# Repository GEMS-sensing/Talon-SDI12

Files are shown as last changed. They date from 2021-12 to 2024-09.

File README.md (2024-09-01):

<!-- [![DOI](https://zenodo.org/badge/678911830.svg)](https://zenodo.org/doi/10.5281/zenodo.13377368) -->

# Talon-SDI12
Talon daughterboard for [Flight data logger](https://github.com/GEMS-sensing/DFM_-_Flight?tab=readme-ov-file). Designed to interface with [Kestrel](https://github.com/GEMS-sensing/Project-Kestrel) main board. This board is designed to provide data logger with support to interface with [SDI-12 communication standard](https://www.sdi-12.org/current_specification/SDI-12%20Specification%201.4%20February%2020%202023.pdf) for environmental sensors.

# Repo Roadmap
#### [Documents](Documents/) 

General document and image storage for repo and README

#### [Hardware](Hardware/)

Current board files (Eagle), Bill of Materials (BoM), and other design documents

#### [Production](Production/)

Contains the various Gerber and pick and place files required to have the Printed Circuit Boards (PCBs) manufactured or populated 

#### [Software](Software/)

The software associated with the piece of hardware, this is usually diagnostic software used for verifying or investigating the hardware

<!-- #### [Mechanical](Mechanical/)

Mechanical design files and assembly documents -->

<!-- #### [Testing](Testing/)

Scripts and results from the testing process and development process. Contains more detailed information about documented issues among other testing. 
 -->

## Overview
* **Type:** Talon
* **Interfaces:** SDI-12
* **Release Version:** v1.4 - 2022/04/25

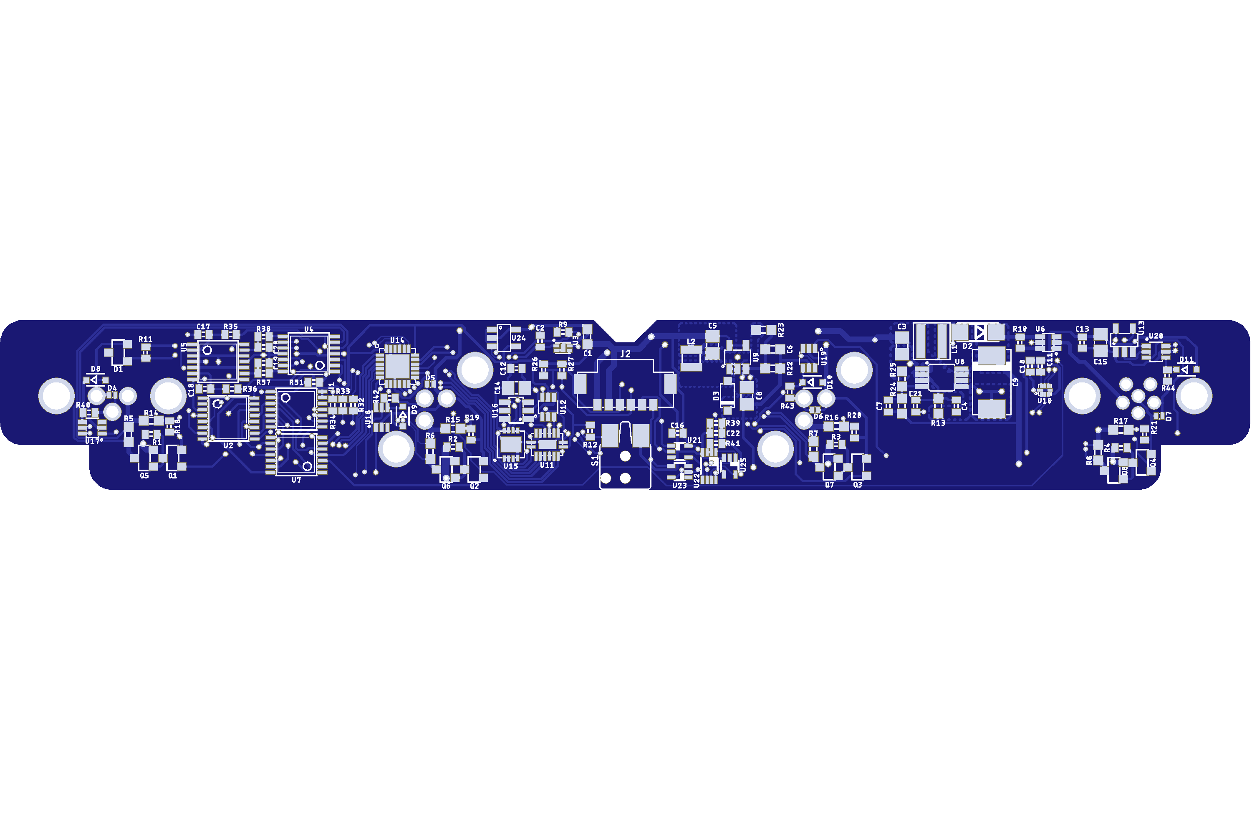
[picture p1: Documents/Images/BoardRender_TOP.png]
PCB render image, top


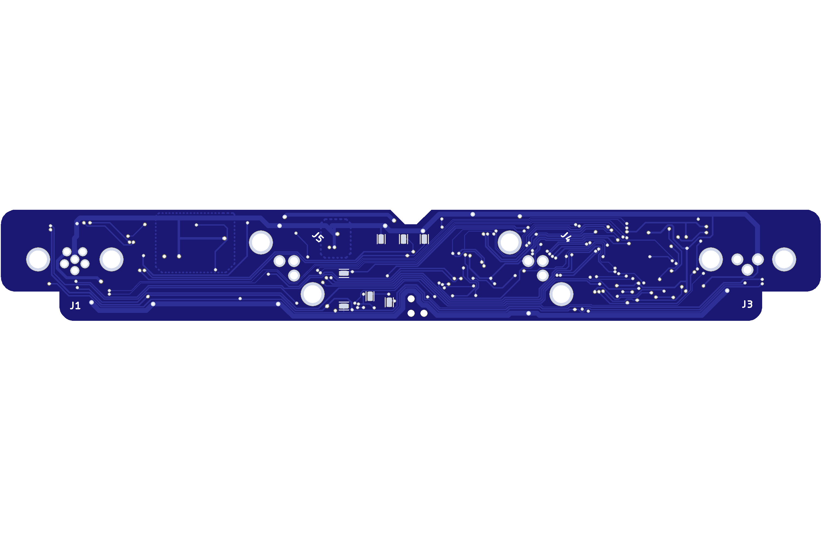
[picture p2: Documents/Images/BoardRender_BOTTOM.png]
PCB render image, bottom


<!-- ![Haar v0.0 - Bottom](Documents/Images/Haar_0v0_Bottom_Cropped.jpg) -->

## Features
### On-Board
* SDI-12 ports (x3)
* Dedicated Apogee sensor port (x1)
	* Supports SDI-12 communication and analog voltage input
	* Supports [Apogee pinout standard](https://www.apogeeinstruments.com/apogee-wiring-guide/)
* Port level current limit
	* Custom designed automatic current limit 
	* support for current and voltage measurement for each port
* Data and power control for each port
* Loopback support to perform SDI-12 communication diagnostics 
* EEPROM with UUID built in - can store additional values defined by firmware to track offsets, etc
* ESD protected inputs

<!-- ### Interface
* I<sup>2</sup>C
* M12 circular connector  -->

<!-- <picture>
  <source media="(prefers-color-scheme: dark)" srcset="Documents/Pinout_LIGHT.png">
  <img alt="Haar Connector Pinout" src="Documents/Pinout.png">
</picture> -->

<!-- ## Specifications
* **Voltage - Supply:** 3.3V
* **Voltage - Logic:** 3.3V
* **Input Current (Avg, 1s period): 30.95&mu;A @ 3.3V**
* **Input Current (Avg, 5s period): 107.43&mu;A @ 3.3V**
* **Input Current (Max): 0.45mA @ 3.3V**

#### Sensor
**Temperature** [^1]
* Range: -40 ~ 125°C 
* Accuracy: &plusmn; 0.2°C
* Repeatability: &plusmn; 0.04°C

**Pressure** [^2]
* Range: 300 ~ 1200 hPa  
* Accuracy: &plusmn; 1 hPa
* Repeatability: &plusmn; 0.06 hPa

**Humidity** [^1]
* Range: 0 ~ 100%
* Accuracy: &plusmn; 2%
* Repeatability: 0.08%

[^1]: [SHT31 Datasheet](https://sensirion.com/media/documents/213E6A3B/63A5A569/Datasheet_SHT3x_DIS.pdf)
[^2]: [DPS368 Datasheet](https://www.infineon.com/dgdl/Infineon-DPS368-DS-v01_00-EN.pdf?fileId=5546d46269e1c019016a0c45105d4b40) -->

<!-- ## Version History

`v0.0` - Initial primal version with screw terminal

`v0.1` - Initial 'hard mount' version, using M12 connector

`v1.0` - Removed pullup select[^3], added logic level buffer and voltage reg on input

`v1.1` - Moved via away from connector pads to prevent bridging when soldering 

`v2.0` - Fixed issue with address select jumper[^3] -->

<!-- ## Jumper Settings 

> [!IMPORTANT]
> Jumper settings valid for version `v2.0` and beyond[^3]

[^3]: See Errata

**Configuration Jumpers**
| Jumper | Purpose | Open | Closed | Default | 
| --- | --- | --- | --- | ----- |
| `JP1` | I<sup>2</sup>C Address Select | Base Address<sup>&dagger;</sup> | Alt Address<sup>&Dagger;</sup> | Open |

&dagger; SHT31 = `0x44`, DPS368 = `0x76`

&Dagger; SHT31 = `0x44`, DPS368 = `0x77`
 -->

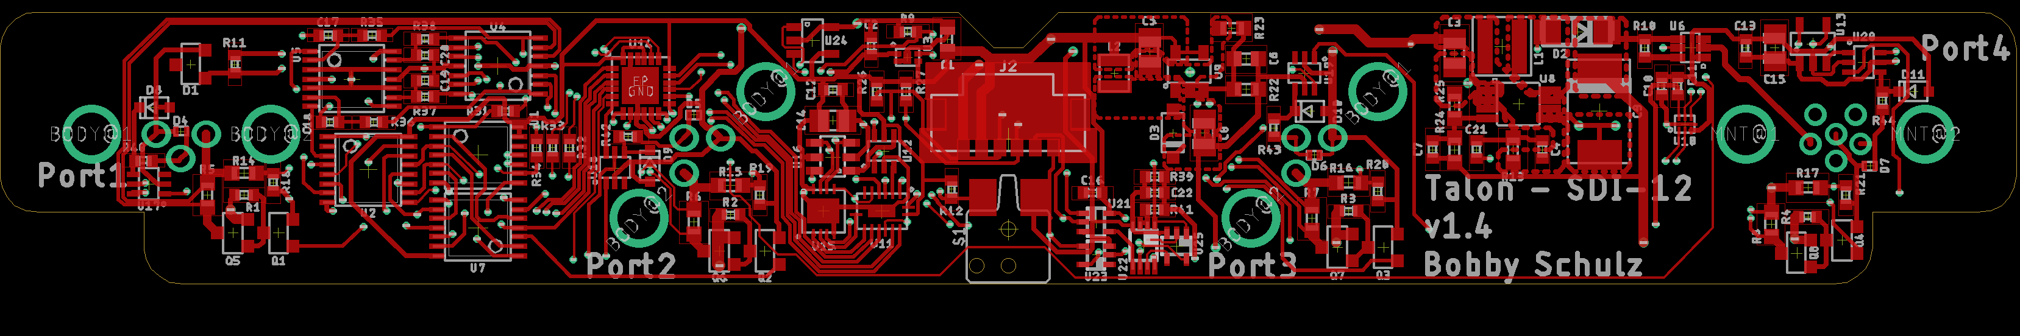
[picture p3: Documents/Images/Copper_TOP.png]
PCB trace CAD image, top


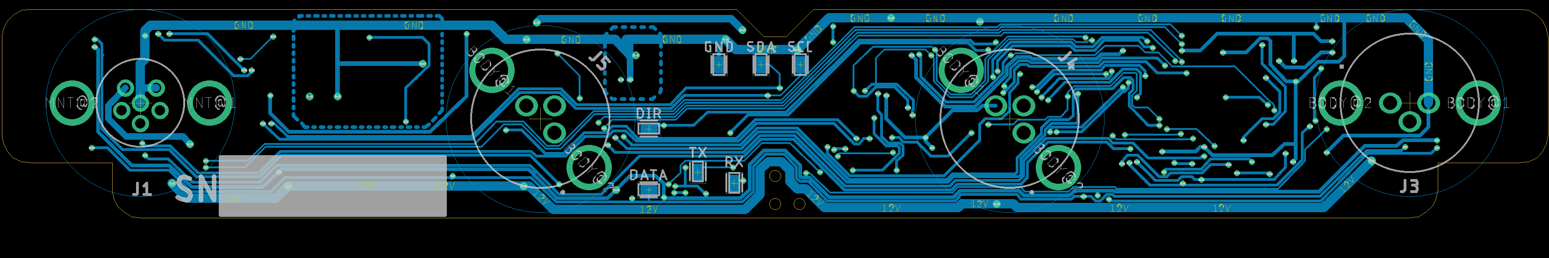
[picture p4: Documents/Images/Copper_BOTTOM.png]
PCB trace CAD, bottom


## Known Issues/Errata

None
<!-- #### Solder Jumper Stencil

**Version Affected:** All

**Issue:** Solar input does not support very low impedance sources (e.g. lead acid battery) - see details in issue [#20](https://github.com/GEMS-sensing/Project-Kestrel/issues/20)

**Workaround:** 

* Avoid use of low impedance batteries for input
* Include series impedance to prevent current spikes (not desirable)
* Perform board patch described in issue [#20](https://github.com/GEMS-sensing/Project-Kestrel/issues/20) -->

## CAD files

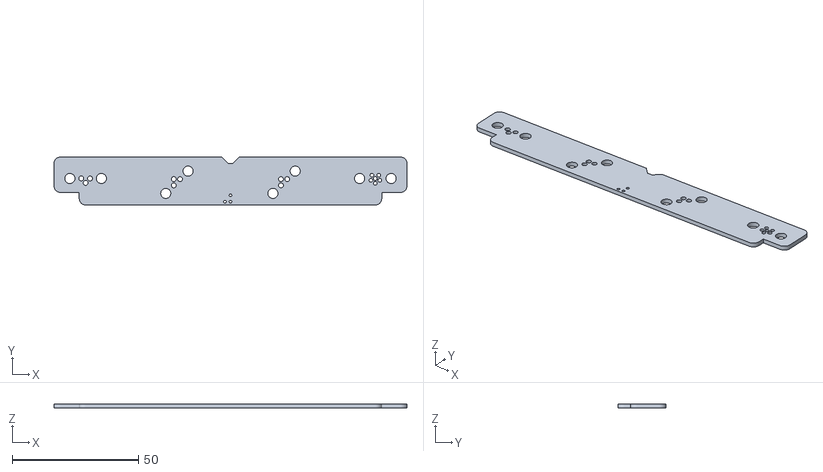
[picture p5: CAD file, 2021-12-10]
Hardware/Talon_SDI12_1v1.STL
140.0 x 19.0 x 1.57

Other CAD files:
Hardware/Talon_SDI12_1v1.dxf

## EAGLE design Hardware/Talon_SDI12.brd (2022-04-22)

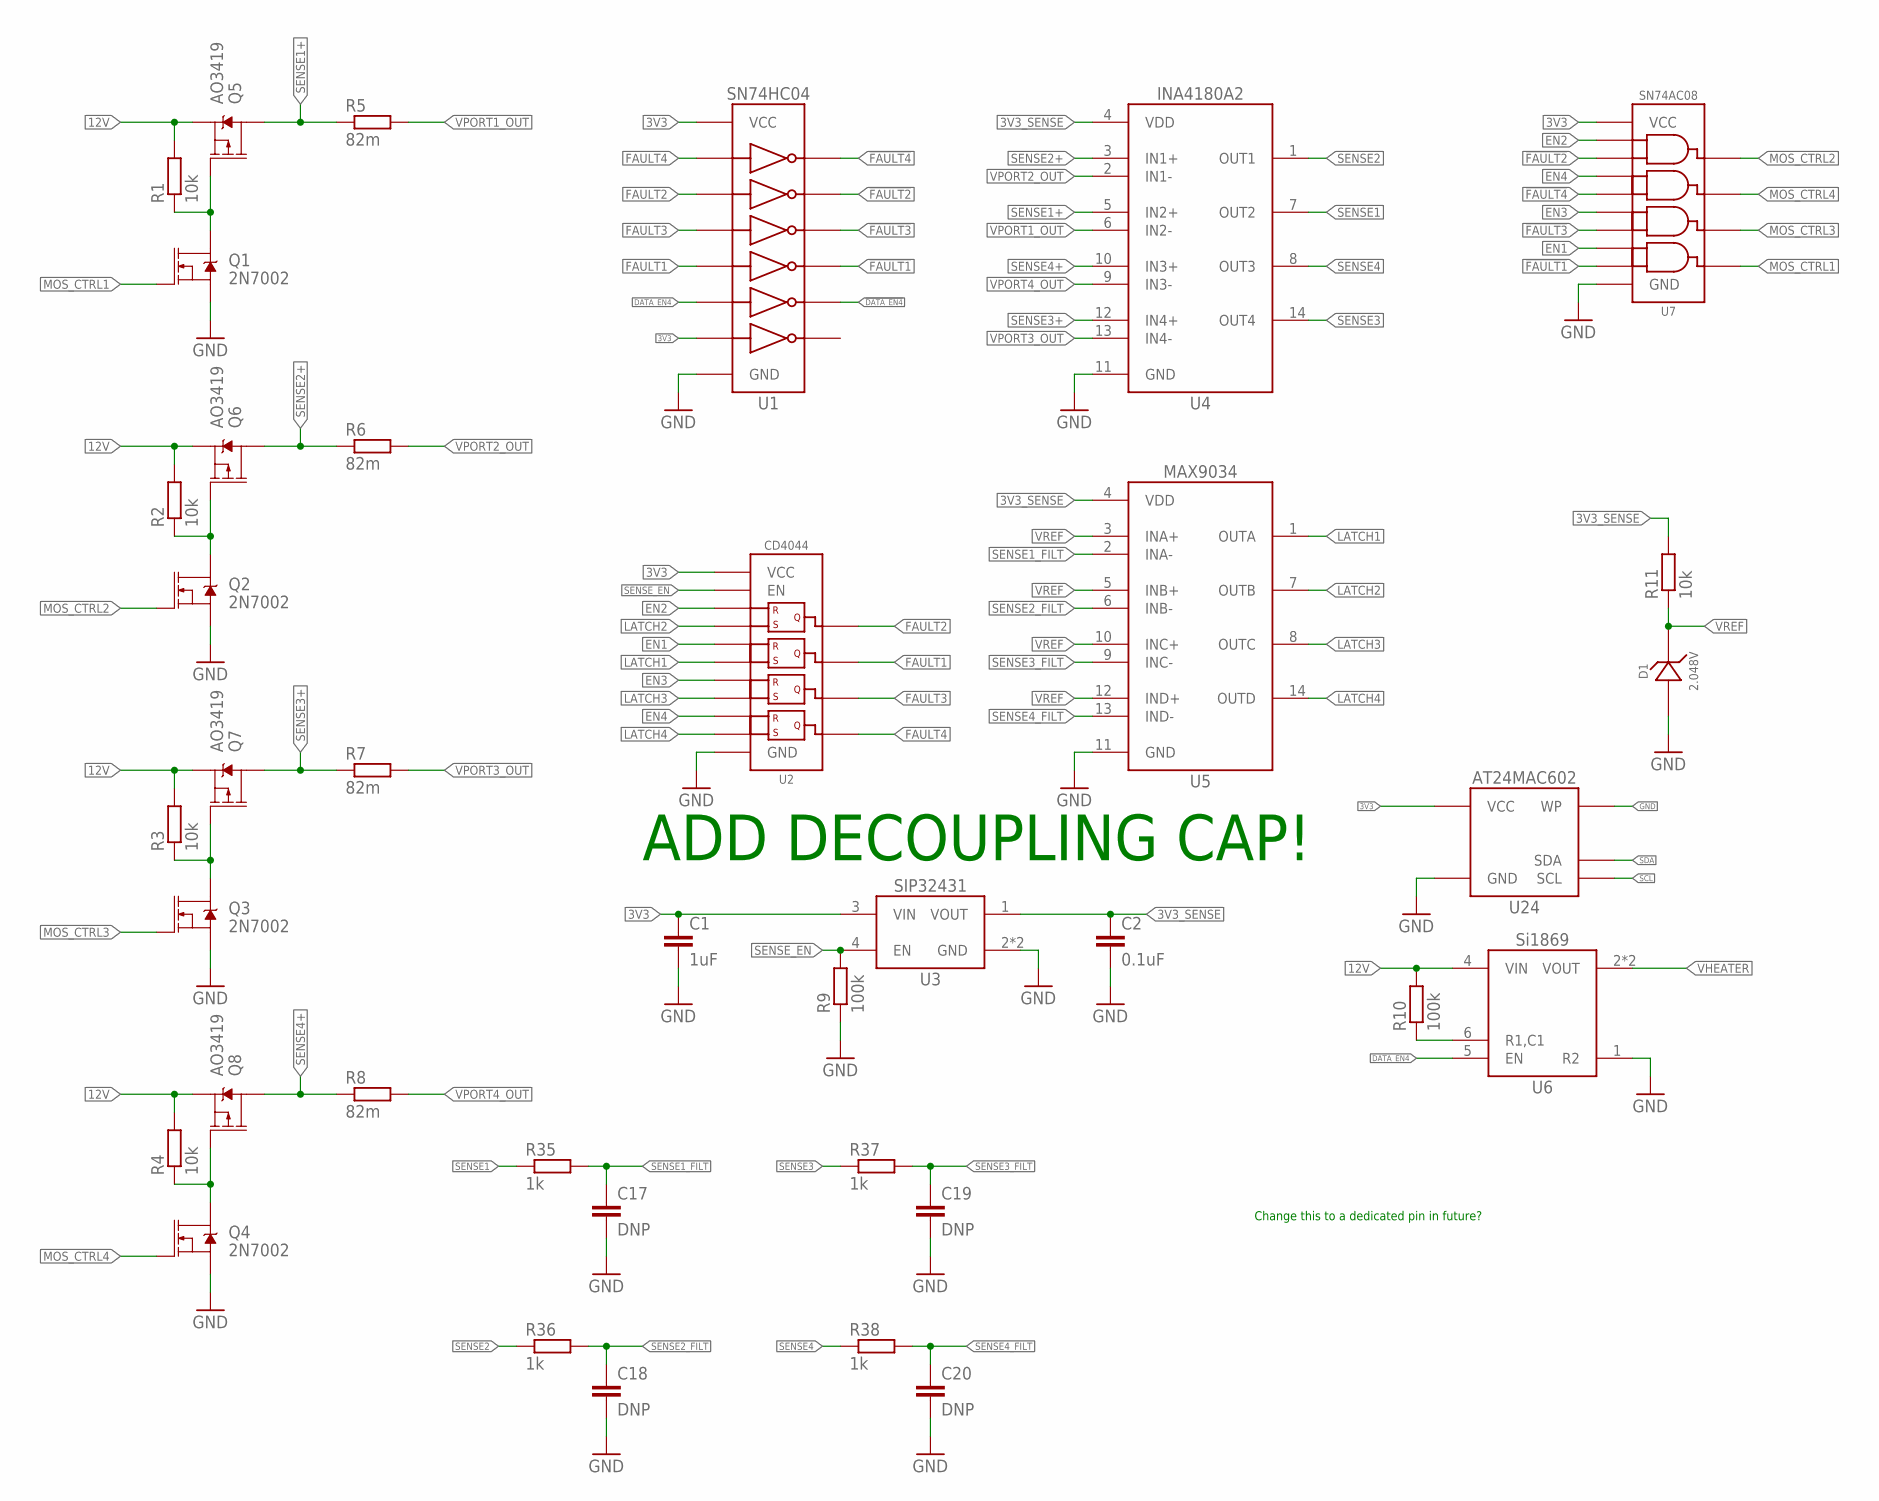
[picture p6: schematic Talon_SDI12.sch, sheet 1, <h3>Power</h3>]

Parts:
C1: 1uF; C0603
C2: 0.1uF; C0402
C17, C18, C19, C20: DNP; C0402; MPN DNP; DIGIKEY DNP
D1: 2.048V; SOT23-3
Q1, Q2, Q3, Q4: 2N7002; SOT23-3
Q5, Q6, Q7, Q8: AO3419; SOT23-3
R1, R2, R3, R4, R11: 10k; R0402
R5, R6, R7, R8: 82m; R0603
R9, R10: 100k; R0402
R35, R36, R37, R38: 1k; R0402
U1: SN74HC04; TSSOP14
U2: CD4044; TSSOP16
U3: SIP32431TDFN; TDFN_4
U4: INA4180A2; TSSOP14
U5: MAX9034TSSOP; TSSOP14
U6: SI1869; SC-70_6
U7: SN74AC08; TSSOP14
U24: AT24MAC602SOT23; SOT23-5

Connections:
3V3: C1.1, U1.13 (A6), U1.14 (VCC), U2.16 (VCC), U3.3 (VIN), U7.14 (VCC), U24.4 (VCC); also elsewhere on the board
3V3_SENSE: C2.1, R11.2, U3.1 (VOUT), U4.4 (VDD), U5.4 (VDD)
12V: Q5.2 (S), Q6.2 (S), Q7.2 (S), Q8.2 (S), R1.2, R2.2, R3.2, R4.2, R10.2, U6.4 (VIN); also elsewhere on the board
!DATA_EN4: U1.10 (Y5); also elsewhere on the board
!FAULT1: U1.8 (Y4), U7.13 (B4)
!FAULT2: U1.4 (Y2), U7.2 (B1)
!FAULT3: U1.6 (Y3), U7.10 (B3)
!FAULT4: U1.2 (Y1), U7.5 (B2)
DATA_EN4: U1.11 (A5), U6.5 (EN); also elsewhere on the board
EN1: U2.6 (R2), U7.12 (A4); also elsewhere on the board
EN2: U2.4 (R1), U7.1 (A1); also elsewhere on the board
EN3: U2.12 (R3), U7.9 (A3); also elsewhere on the board
EN4: U2.14 (R4), U7.4 (A2); also elsewhere on the board
FAULT1: U1.9 (A4), U2.9 (Q2); also elsewhere on the board
FAULT2: U1.3 (A2), U2.13 (Q1); also elsewhere on the board
FAULT3: U1.5 (A3), U2.10 (Q3); also elsewhere on the board
FAULT4: U1.1 (A1), U2.1 (Q4); also elsewhere on the board
GND: C1.2, C2.2, C17.2, C18.2, C19.2, C20.2, D1.2 (A), Q1.2 (S), Q2.2 (S), Q3.2 (S), Q4.2 (S), R9.1, U1.7 (GND), U2.8 (GND), U3.2 (GND), U3.EP (GND), U4.11 (GND), U5.11 (GND), U6.1 (R2), U7.7 (GND), U24.2 (GND), U24.5 (WP); also elsewhere on the board
LATCH1: U2.7 (S2), U5.1 (OUTA)
LATCH2: U2.3 (S1), U5.7 (OUTB)
LATCH3: U2.11 (S3), U5.8 (OUTC)
LATCH4: U2.15 (S4), U5.14 (OUTD)
MOS_CTRL1: Q1.1 (G), U7.11 (Y4)
MOS_CTRL2: Q2.1 (G), U7.3 (Y1)
MOS_CTRL3: Q3.1 (G), U7.8 (Y3)
MOS_CTRL4: Q4.1 (G), U7.6 (Y2)
unnamed: Q2.3 (D), Q6.1 (G), R2.1
unnamed: Q1.3 (D), Q5.1 (G), R1.1
unnamed: Q3.3 (D), Q7.1 (G), R3.1
unnamed: Q4.3 (D), Q8.1 (G), R4.1
unnamed: R10.1, U6.6 (R1,C1)
SCL: U24.1 (SCL); also elsewhere on the board
SDA: U24.3 (SDA); also elsewhere on the board
SENSE1: R35.1, U4.7 (OUT2); also elsewhere on the board
SENSE1+: Q5.3 (D), R5.1, U4.5 (IN2+)
SENSE1_FILT: C17.1, R35.2, U5.2 (INA-)
SENSE2: R36.1, U4.1 (OUT1); also elsewhere on the board
SENSE2+: Q6.3 (D), R6.1, U4.3 (IN1+)
SENSE2_FILT: C18.1, R36.2, U5.6 (INB-)
SENSE3: R37.1, U4.14 (OUT4); also elsewhere on the board
SENSE3+: Q7.3 (D), R7.1, U4.12 (IN4+)
SENSE3_FILT: C19.1, R37.2, U5.9 (INC-)
SENSE4: R38.1, U4.8 (OUT3); also elsewhere on the board
SENSE4+: Q8.3 (D), R8.1, U4.10 (IN3+)
SENSE4_FILT: C20.1, R38.2, U5.13 (IND-)
SENSE_EN: R9.2, U2.5 (EN), U3.4 (EN); also elsewhere on the board
VHEATER: U6.2 (VOUT), U6.3 (VOUT); also elsewhere on the board
VPORT1_OUT: R5.2, U4.6 (IN2-); also elsewhere on the board
VPORT2_OUT: R6.2, U4.2 (IN1-); also elsewhere on the board
VPORT3_OUT: R7.2, U4.13 (IN4-); also elsewhere on the board
VPORT4_OUT: R8.2, U4.9 (IN3-); also elsewhere on the board
VREF: D1.1 (C), R11.1, U5.3 (INA+), U5.5 (INB+), U5.10 (INC+), U5.12 (IND+)

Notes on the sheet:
ADD DECOUPLING CAP!
Change this to a dedicated pin in future?

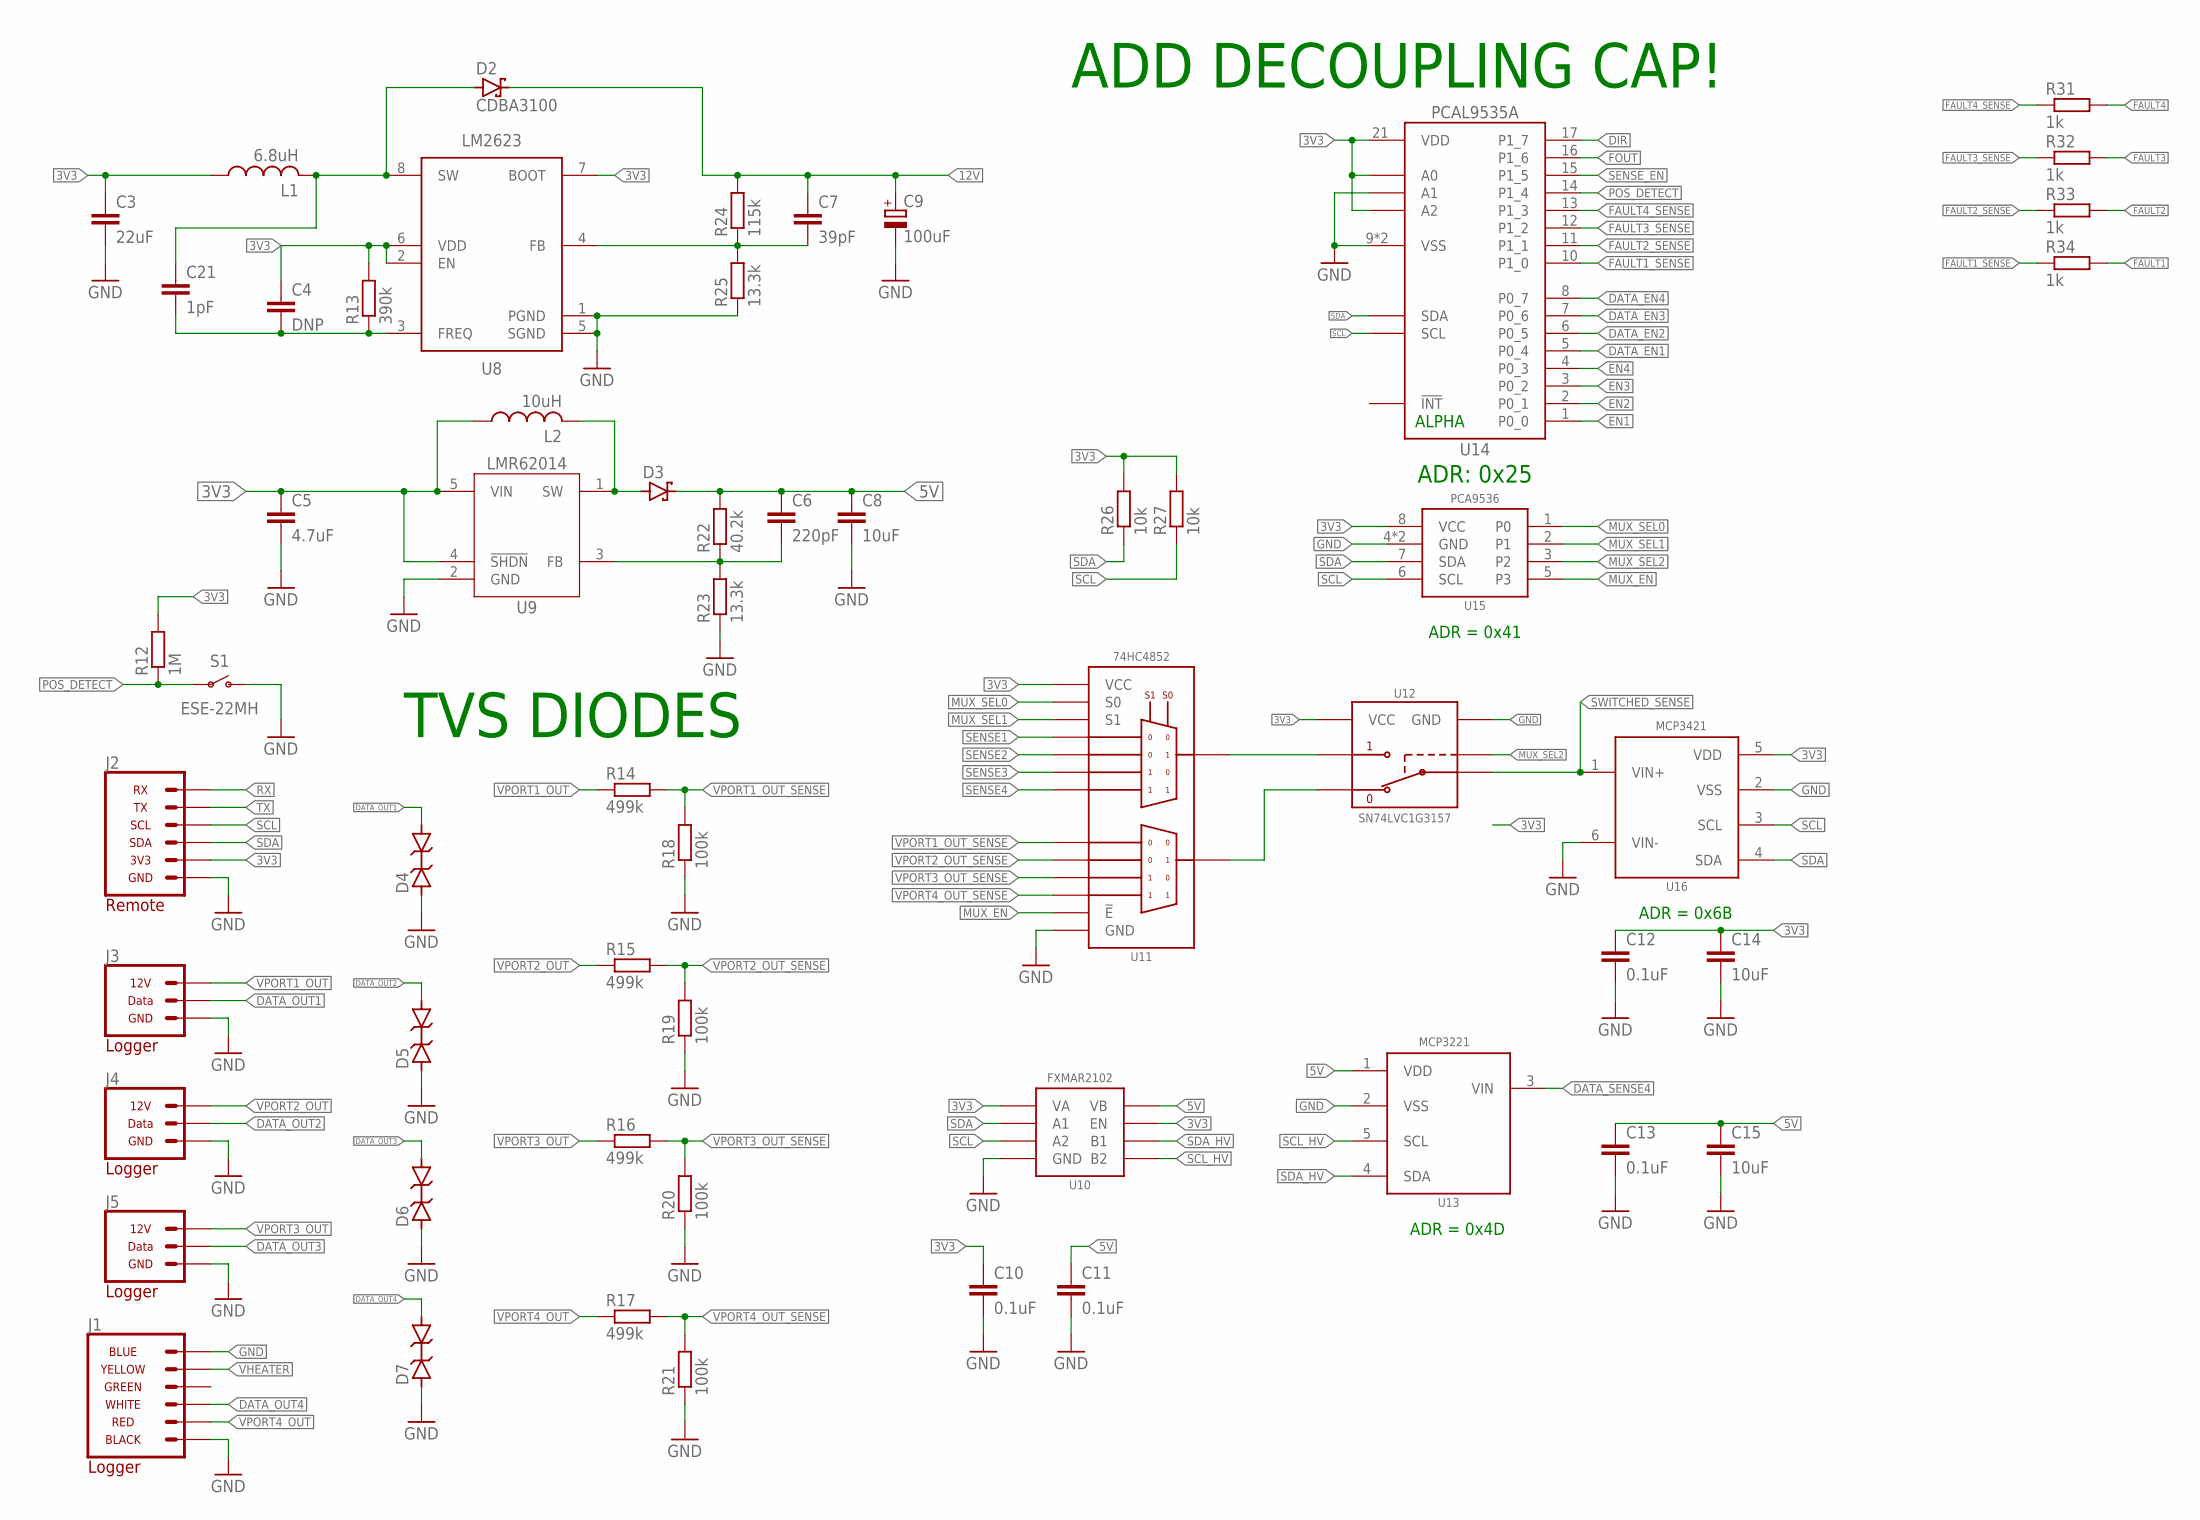
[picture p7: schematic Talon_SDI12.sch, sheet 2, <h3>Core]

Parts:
C3: 22uF; C0805
C4: DNP; C0402; MPN DNP; DIGIKEY DNP
C5: 4.7uF; C0805
C6: 220pF; C0603
C7: 39pF; C0402
C8: 10uF; C0805; MPN TMK212BBJ106KG-T; DIGIKEY 587-2985-1-ND
C9: 100uF; C2917; MPN 293D107X0016D2TE3; DIGIKEY 718-293D107X0016D2TE3CT-ND
C10, C11, C12, C13: 0.1uF; C0402
C14, C15: 10uF; C0805
C21: 1pF; C0402
D2: CDBA3100; DO214AC; MPN CDBA3100-HF; DIGIKEY 641-1747-1-ND
D3: DIODE_SCHOTTKYSOD-123; SOD-123; MPN MBR0520LT1G; DIGIKEY MBR0520LT1GOSCT-ND
D4, D5, D6, D7: 12V; D0402; MPN D12V0L1B2LP-7B; DIGIKEY D12V0L1B2LP-7BDICT-ND
J1: CONN_APOGEE_LOGGER; 1X06_M8_PHOENIX_1456022_BOARDLOCK
J2: CONN_TALON_REMOTE; 1X06_MICROLOCKPLUS
J3, J4, J5: CONN_SDI-12_LOGGERM8_TE_BOARDLOCK; 1X03_M8_TE_T40410_BOARDLOCK
L1: 6.8uH; WE-MAIA(4.1X4.1); MPN 78438357068; DIGIKEY 732-11744-1-ND
L2: 10uH; 1008; MPN 74438323100; DIGIKEY 732-4851-1-ND
R12: 1M; R0402
R13: 390k; R0603
R14, R15, R16, R17: 499k; R0603
R18, R19, R20, R21: 100k; R0402
R22: 40.2k; R0603
R23, R25: 13.3k; R0603
R24: 115k; R0603
R26, R27: 10k; R0402
R31, R32, R33, R34: 1k; R0402
S1: ESE-22MH
U8: LM2621; DGK_S-PDSO-G8; MPN LM2623AMM/NOPB; DIGIKEY LM2623AMM/NOPBCT-ND
U9: LMR62014SOT23; DBV0005A
U10: FXMAR2102UMLP; UQFN-8_1.4X1.2
U11: 74HC4852; VQFN-16
U12: SN74LVC1G3157SC70; DCK_R-PDSO-G6
U13: MCP3221; SOT23-5
U14: PCAL9535AQFN; QFN24
U15: PCA9536DFN; DFN_8_3X3
U16: MCP3421A3; SOT23-6L

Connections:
3V3: C3.1, C4.1, C5.1, C10.1, C12.1, C14.1, J2.2 (3V3), L1.P$1 (1), L2.1, R12.2, R13.2, R26.2, R27.2, U8.2 (EN), U8.6 (VDD), U8.7 (BOOT), U9.4 (!SHDN), U9.5 (VIN), U10.1 (VA), U10.5 (EN), U11.16 (VCC), U12.5 (VCC), U14.18 (A0), U14.21 (VDD), U14.24 (A2), U15.8 (VCC), U16.5 (VDD); also elsewhere on the board
5V: C6.1, C8.1, C11.1, C13.1, C15.1, D3.CAT (C), R22.2, U10.8 (VB), U13.1 (VDD); also elsewhere on the board
12V: C7.1, C9.+, D2.C, R24.2; also elsewhere on the board
DATA_EN1: U14.5 (P0_4); also elsewhere on the board
DATA_EN2: U14.6 (P0_5); also elsewhere on the board
DATA_EN3: U14.7 (P0_6); also elsewhere on the board
DATA_EN4: U14.8 (P0_7); also elsewhere on the board
DATA_OUT1: D4.2 (C), J3.4 (DATA); also elsewhere on the board
DATA_OUT2: D5.2 (C), J4.4 (DATA); also elsewhere on the board
DATA_OUT3: D6.2 (C), J5.4 (DATA); also elsewhere on the board
DATA_OUT4: D7.2 (C), J1.3; also elsewhere on the board
DATA_SENSE4: U13.3 (VIN); also elsewhere on the board
DIR: U14.17 (P1_7); also elsewhere on the board
EN1: U14.1 (P0_0); also elsewhere on the board
EN2: U14.2 (P0_1); also elsewhere on the board
EN3: U14.3 (P0_2); also elsewhere on the board
EN4: U14.4 (P0_3); also elsewhere on the board
FAULT1: R34.2; also elsewhere on the board
FAULT1_SENSE: R34.1, U14.10 (P1_0)
FAULT2: R33.2; also elsewhere on the board
FAULT2_SENSE: R33.1, U14.11 (P1_1)
FAULT3: R32.2; also elsewhere on the board
FAULT3_SENSE: R32.1, U14.12 (P1_2)
FAULT4: R31.2; also elsewhere on the board
FAULT4_SENSE: R31.1, U14.13 (P1_3)
FOUT: U14.16 (P1_6); also elsewhere on the board
GND: C3.2, C5.2, C8.2, C9.-, C10.2, C11.2, C12.2, C13.2, C14.2, C15.2, D4.1 (A), D5.1 (A), D6.1 (A), D7.1 (A), J1.1, J1.6, J2.1 (GND), J3.3 (GND), J4.3 (GND), J5.3 (GND), R18.1, R19.1, R20.1, R21.1, R23.1, R25.1, S1.1 (O), U8.1 (PGND), U8.5 (SGND), U9.2 (GND), U10.4 (GND), U11.8 (GND), U11.EP (GND), U12.2 (GND), U13.2 (VSS), U14.9 (VSS), U14.23 (A1), U14.EP (VSS), U15.4 (GND), U15.EP (GND), U16.2 (VSS), U16.6 (VIN-); also elsewhere on the board
MUX_EN: U11.6 (!E), U15.5 (P3); also elsewhere on the board
MUX_SEL0: U11.10 (S0), U15.1 (P0)
MUX_SEL1: U11.9 (S1), U15.2 (P1)
MUX_SEL2: U12.6 (S), U15.3 (P2)
unnamed: C4.2, C21.2, R13.1, U8.3 (FREQ)
unnamed: C21.1, D2.A, L1.P$2 (2), U8.8 (SW)
unnamed: C7.2, R24.1, R25.2, U8.4 (FB)
unnamed: C6.2, R22.1, R23.2, U9.3 (FB)
unnamed: U11.3 (2Z), U12.3 (B1)
unnamed: U11.13 (1Z), U12.1 (B2)
POS_DETECT: R12.1, S1.2, U14.14 (P1_4)
RX: J2.6 (RX); also elsewhere on the board
SCL: J2.4 (SCL), R27.1, U10.3 (A2), U14.19 (SCL), U15.6 (SCL), U16.3 (SCL); also elsewhere on the board
SCL_HV: U10.6 (B2), U13.5 (SCL)
SDA: J2.3 (SDA), R26.1, U10.2 (A1), U14.20 (SDA), U15.7 (SDA), U16.4 (SDA); also elsewhere on the board
SDA_HV: U10.7 (B1), U13.4 (SDA)
SENSE1: U11.12 (1Y0); also elsewhere on the board
SENSE2: U11.14 (1Y1); also elsewhere on the board
SENSE3: U11.15 (1Y2); also elsewhere on the board
SENSE4: U11.11 (1Y3); also elsewhere on the board
SENSE_EN: U14.15 (P1_5); also elsewhere on the board
SW1: D3.ANODE (A), L2.2, U9.1 (SW)
SWITCHED_SENSE: U12.4 (A), U16.1 (VIN+)
TX: J2.5 (TX); also elsewhere on the board
VHEATER: J1.5; also elsewhere on the board
VPORT1_OUT: J3.1 (12V), R14.1; also elsewhere on the board
VPORT1_OUT_SENSE: R14.2, R18.2, U11.1 (2Y0)
VPORT2_OUT: J4.1 (12V), R15.1; also elsewhere on the board
VPORT2_OUT_SENSE: R15.2, R19.2, U11.5 (2Y1)
VPORT3_OUT: J5.1 (12V), R16.1; also elsewhere on the board
VPORT3_OUT_SENSE: R16.2, R20.2, U11.2 (2Y2)
VPORT4_OUT: J1.2, R17.1; also elsewhere on the board
VPORT4_OUT_SENSE: R17.2, R21.2, U11.4 (2Y3)

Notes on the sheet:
ALPHA
ADD DECOUPLING CAP!
TVS DIODES
ADR: 0x25
ADR = 0x6B
ADR = 0x4D
ADR = 0x41

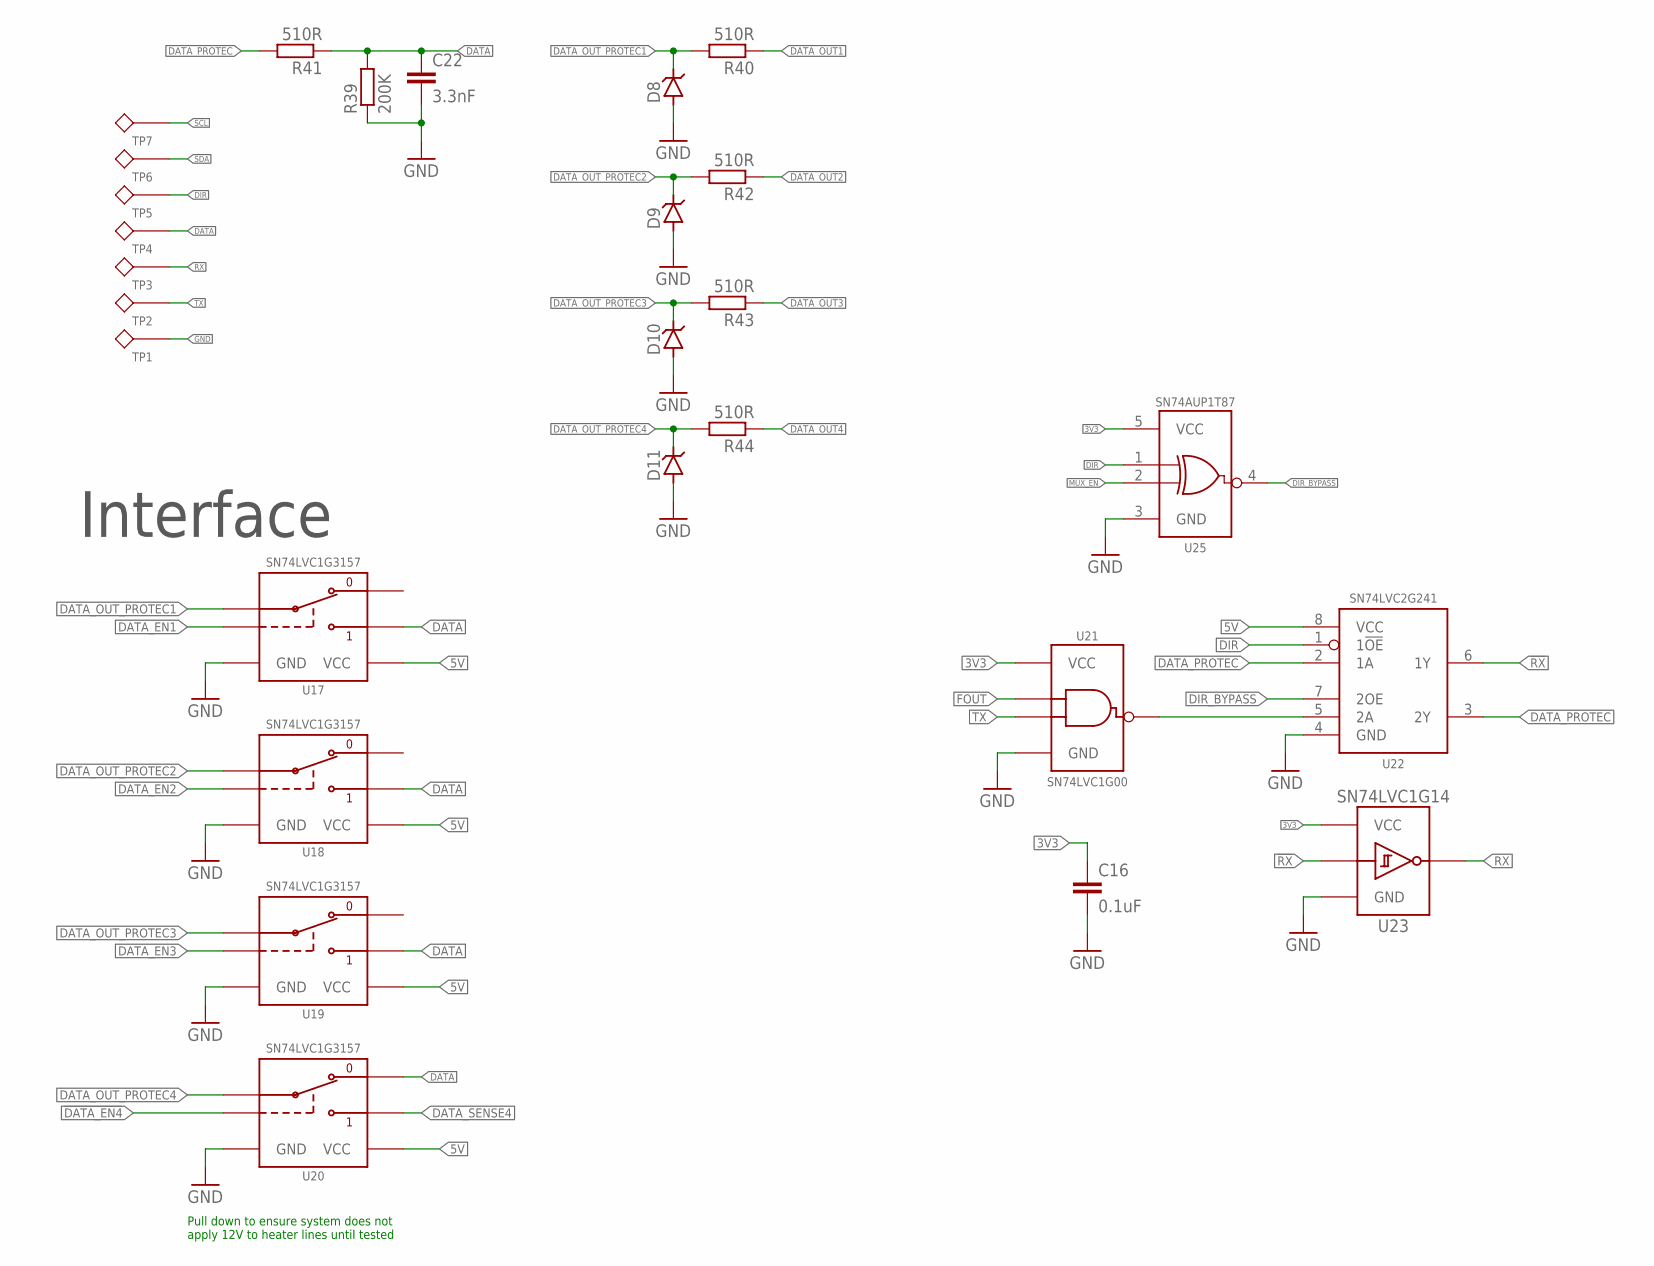
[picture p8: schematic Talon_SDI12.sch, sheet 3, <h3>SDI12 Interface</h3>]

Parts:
C16: 0.1uF; C0402
C22: 3.3nF; C0402
D8, D9, D10, D11: DIODE_ZENERSOD-323; SOD323-R; MPN BZX384B5V1-HE3-08; DIGIKEY BZX384B5V1-HE3-08GICT-ND
R39: 200K; R0402
R40, R41, R42, R43, R44: 510R; R0402
TP1, TP2, TP3, TP4, TP5, TP6, TP7: TESTPOINTRCU; TESTPOINT_0603
U17, U18, U19, U20: SN74LVC1G3157SC70; DCK_R-PDSO-G6
U21: SN74LVC1G00SC70; DCK_R-PDSO-G5
U22: SN74LVC2G241DCU; DCU_(R-PDSO-G8)
U23: SN74LVC1G14DCK; DCK_R-PDSO-G5
U25: SN74AUP1T87; DCK_R-PDSO-G5

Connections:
3V3: C16.1, U21.5 (VCC), U23.5 (VCC), U25.5 (VCC); also elsewhere on the board
5V: U17.5 (VCC), U18.5 (VCC), U19.5 (VCC), U20.5 (VCC), U22.8 (VCC); also elsewhere on the board
!DATA_EN4: U20.6 (S); also elsewhere on the board
!RX: U22.6 (1Y), U23.2 (A)
DATA: C22.1, R39.2, R41.1, TP4.1, U17.1 (B2), U18.1 (B2), U19.1 (B2), U20.3 (B1)
DATA_EN1: U17.6 (S); also elsewhere on the board
DATA_EN2: U18.6 (S); also elsewhere on the board
DATA_EN3: U19.6 (S); also elsewhere on the board
DATA_OUT1: R40.1; also elsewhere on the board
DATA_OUT2: R42.1; also elsewhere on the board
DATA_OUT3: R43.1; also elsewhere on the board
DATA_OUT4: R44.1; also elsewhere on the board
DATA_OUT_PROTEC1: D8.C, R40.2, U17.4 (A)
DATA_OUT_PROTEC2: D9.C, R42.2, U18.4 (A)
DATA_OUT_PROTEC3: D10.C, R43.2, U19.4 (A)
DATA_OUT_PROTEC4: D11.C, R44.2, U20.4 (A)
DATA_PROTEC: R41.2, U22.2 (1A), U22.3 (2Y)
DATA_SENSE4: U20.1 (B2); also elsewhere on the board
DIR: TP5.1, U22.1 (1!OE), U25.1 (A); also elsewhere on the board
DIR_BYPASS: U22.7 (2OE), U25.4 (Y)
FOUT: U21.1 (A); also elsewhere on the board
GND: C16.2, C22.2, D8.A, D9.A, D10.A, D11.A, R39.1, TP1.1, U17.2 (GND), U18.2 (GND), U19.2 (GND), U20.2 (GND), U21.3 (GND), U22.4 (GND), U23.3 (GND), U25.3 (GND); also elsewhere on the board
MUX_EN: U25.2 (B); also elsewhere on the board
unnamed: U21.4 (Y), U22.5 (2A)
RX: TP3.1, U23.4 (Y); also elsewhere on the board
SCL: TP7.1; also elsewhere on the board
SDA: TP6.1; also elsewhere on the board
TX: TP2.1, U21.2 (B); also elsewhere on the board

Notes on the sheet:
Interface
Pull down to ensure system does not apply 12V to heater lines until tested

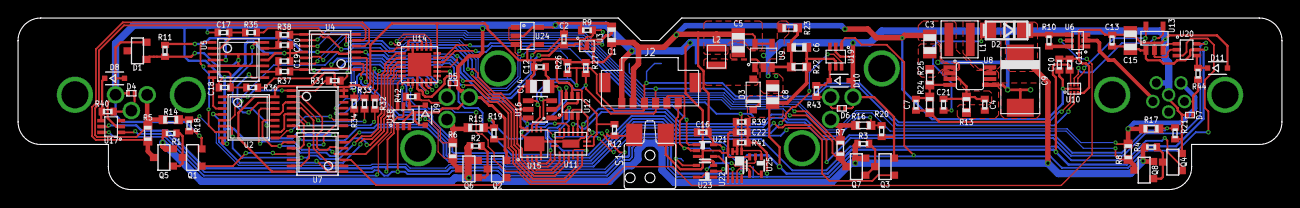
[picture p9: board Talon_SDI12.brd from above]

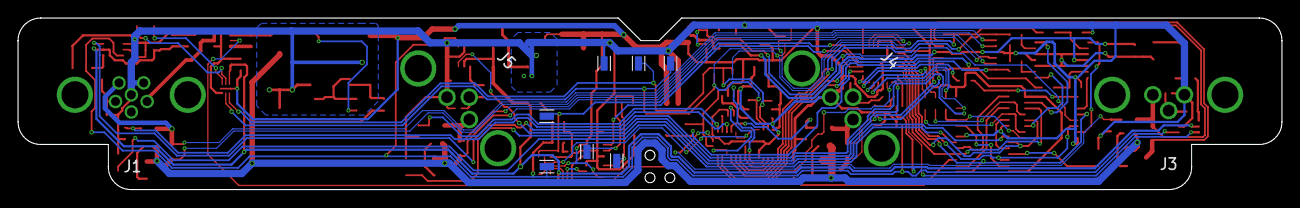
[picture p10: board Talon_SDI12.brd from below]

Board: 2 copper layers, 140.0 x 19.0 mm, 122 parts (11 on the bottom side), 97 nets.

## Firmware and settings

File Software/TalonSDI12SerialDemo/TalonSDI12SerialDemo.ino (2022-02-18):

#include <Wire.h>
#include <Arduino.h>
#include <MCP23018.h>

// #define NUM_MCP2301x_ICs   1

//Input Pins
const uint8_t TX = 1;
const uint8_t RX = 0;

//IO Expander Pins
const uint8_t FOut = 14;
const uint8_t Dir = 15;

const uint8_t POS_DETECT = 12;
const uint8_t SENSE_EN = 13;

const uint8_t DATA_EN1 = 4;
const uint8_t EN1 = 0;
const uint8_t FAULT1 = 8;

//Configured for pins on the Particle Boron
//const uint8_t EXT_EN = 8;
//const uint8_t SDA_CTRL = 2;

const uint8_t EXT_EN = 13;
const uint8_t SDA_CTRL = 5;

#define MARKING_PERIOD 9 //>8.33ms for standard marking period
const unsigned long TimeoutStandard = 380; //Standard timeout period for most commands is 380ms 

char ReadArray[25] = {0};

MCP23018 io(0x26); //FIX??
// MCP2301x io;

// #define IOEXP_MODE  (IOCON_INTCC | IOCON_INTPOL | IOCON_ODR | IOCON_MIRROR)
// #define ADDRESS      (MCP2301X_CTRL_ID+7)
// #define LED_PIN      D4   // WeMOS D1 & D1 mini
// #define IN_PORT      0
// #define OUT_PORT     1

// #define RELAY_ON      LOW
// #define RELAY_OFF     HIGH
// #define ALL_OFF       ALL_LOW

// #define DIR 0x00
// #define GPIO 0x12
// #define LAT 0x14
// #define PU 0x0C
// #define ADR 0x20

///////////// VOLTAGE SENSE /////////////
#include <SparkFun_PCA9536_Arduino_Library.h>
#include <MCP3421.h>

MCP3421 adc(0x6B); //Initialize MCP3421 with A3 address

PCA9536 ioSense;

//IO Sense pins
const uint8_t MUX_EN = 3;
const uint8_t MUX_SEL0 = 0;
const uint8_t MUX_SEL1 = 1;
const uint8_t MUX_SEL2 = 2;

const float VoltageDiv = 6; //Program voltage divider
const float CurrentDiv = 0.243902439; //82mOhm, 50V/V Amp

///////////// AUX VOLTAGE SENSE /////////////
#include <MCP3221.h>

MCP3221 adcAux(0x4D); //Instantiate MCP3221 with A5 address 

void setup() {

	// pinMode(EXT_EN, OUTPUT); 
	// digitalWrite(EXT_EN, HIGH);
	Serial.begin(115200);
	// delay(5000);
	// pinMode(SDA_CTRL, OUTPUT);
	// digitalWrite(SDA_CTRL, LOW);
	delay(5000);

	Wire.begin();
 //DEBUG1!
	SetDefaultPins(); //Set the default configuration for sensing 
	// SetPinMode();
	// SetPullups();
	// io.digitalWrite(6, HIGH); //Turn on 5V
	// io.digitalWrite(7, HIGH); //Turn on 12V
	// io.digitalWrite(2, LOW); //Enable Data 1
	// io.digitalWrite(3, LOW); //Enable Data 2
	// io.digitalWrite(4, LOW); //Enable Data 3
	//DEBUG1!
	// Wire.beginTransmission(0x20);
	// Wire.write(0x0A);
	// Wire.write(0x80);
	// Wire.endTransmission();

	// io.begin();	
	// Serial.println(io.init(0x20, IOEXP_MODE, I2C_FREQ100K));

	// io.pinPolarityPort(0, ALL_NORMAL);
 //  	io.pinModePort(0,ALL_OUTPUT); 
 //  	// io.pinModePort(IN_PORT,ALL_INPUT);
 //  	io.digitalWritePort(0, ALL_HIGH);
	pinMode(TX, OUTPUT); //DEBUG1!

	// io.pinPullup(0, DATA_EN1, PU_ENABLE);
	// io.pinPullup(0, DATA_EN2, PU_ENABLE);
	// io.pinPullup(0, DATA_EN3, PU_ENABLE);
	// io.pullUp(DATA_EN1, true);
	// io.pullUp(DATA_EN2, true);
	// io.pullUp(DATA_EN3, true);

	// io.pinMode(0, DATA_EN1, OUTPUT);
	// io.pinMode(0, DATA_EN2, OUTPUT);
	// io.pinMode(0, DATA_EN3, OUTPUT);

	// io.digitalWrite( DATA_EN1, HIGH);
	// io.digitalWrite( DATA_EN2, HIGH);
	// io.digitalWrite( DATA_EN3, HIGH);

	// io.pullUp(FOut, true);
	// io.pullUp(Dir, true);
	// io.pinPullup(0, FOut, true);
	// io.pinPullup(0, Dir, true);
	// io.pinMode(0, FOut, OUTPUT);
	// io.pinMode(0, Dir, OUTPUT);
	io.pinMode( Dir, OUTPUT); //Set to output 
	io.pinMode( FOut, OUTPUT); //Set to output 
	io.digitalWrite( Dir, HIGH); //Set to transmit 
//  io.digitalWrite( FOut, LOW); //DEBUG!
	Serial1.begin(1200, SERIAL_7E1);
	
	delay(1000);
	Serial.println("Begin SDI Demo...");
}

void loop() {
	// io.pinMode(0, TX, LOW);
	// io.pinMode(0, FOut, LOW);
	// delay(1000);
	// io.pinMode(0, FOut, LOW);
	// io.pinMode(0, TX, HIGH);
	// delay(1000);
	// io.pinMode(0, FOut, HIGH);
	// io.pinMode(0, TX, LOW);
	// delay(1000);
	// io.pinMode(0, FOut, HIGH);
	// io.pinMode(0, TX, HIGH);
	// delay(1000);
	static int ReadLength = 0;
  	String ReadString;
	if(Serial.available() > 0) {
    char Input = Serial.read();

    // Increment counter while waiting for carrage return or newline
    // if(Input != 13 || Input != 10) {
    if(Input != '#' && Input != '!') { //Wait for SDI12 line end or control line end 
//      Serial.println(Input); //DEBUG!
      ReadArray[ReadLength] = Input;
//      Serial.println(ReadArray[ReadLength]); //DEBUG!
      ReadLength++;
    }

    // if(Input == 13 || Input == 10) { // carriage or newline
    if(Input == '!') { //SDI12 line ending
		ReadArray[ReadLength] = Input; //Append final character
		ReadLength++;

		ReadString = String(ReadArray);
		ReadString.trim();
		memset(ReadArray, 0, sizeof(ReadArray));
		ReadLength = 0;

		// while(Serial.peek() != '\n'); //Wait for new command
		// String NewCommand = Serial.readStringUntil('\n');
		Serial.print(">");
		Serial.println(ReadString); //Echo back to serial monitor
		Serial.println(SendCommand(ReadString));
	}
	//Format - ppCs#
	//pp - two digit pin number (base 10)
	//C - command ('M' - Mode, 'R' - Read, 'W' - Write)
	//s - state (0 - Output/Off, 1 - Input/On), required only for write and mode operations 
	if(Input == '#') { //Control line ending
		ReadString = String(ReadArray);
		ReadString.trim();
		memset(ReadArray, 0, sizeof(ReadArray));
		ReadLength = 0;
		int Pin = (ReadString.substring(0,2)).toInt(); //Grab the pin to operate on
		String Operation = ReadString.substring(2,3); //Grab the middle char
		int State = (ReadString.substring(3,4)).toInt(); //Grab the state to set
		int Result = 0; //Used to grab result of either setting of pin mode or response from a read

		if(Operation.equals("M")) { //if call is for pinmode setting
			Result = io.pinMode(Pin, !State); //Use inverse of state to corespond with 1 = input, 0 = output
		}
		
		if(Operation.equals("R")) { //If call is for digital read
			Result = io.digitalRead(Pin);
		}

		if(Operation.equals("W")) { //If call is for digital write
			Result = io.digitalWrite(Pin, State);
		}

		if(!Operation.equals("S") && !Operation.equals("s")) { //If any function but voltage sense called, report normally
			Serial.print(">");
			Serial.println(ReadString); //Echo back to serial monitor
			Serial.print(">");
			Serial.println(Result); //Return various result 
		}

		if(Operation.equals("S")) { //Run voltage sense program
			VoltageSense();
		}

		if(Operation.equals("s")) { //Run Apogee port voltage sense program
			AuxVoltageSense();
		}
		
	}
	// GetAddress();
	// delay(5000);

}
}

char GetAddress()
{
	SendBreak(); //Send break to start message
	Mark(MARKING_PERIOD); //Mark for standard period before command
	Serial1.begin(1200, SERIAL_7E1);
	Serial1.print("0I!");
	Serial1.flush(); //Make sure data is transmitted before releasing the bus
	delay(1);
	ReleaseBus(); //Switch bus to recieve 
	// char Var = Serial.re

	unsigned long LocalTime = millis();
	// bool GotData = false;
	while(Serial1.available() < 3 && (millis() - LocalTime) <  TimeoutStandard);
	String Val = Serial1.readStringUntil('\r');
	Serial.println(Val);
	return 0; //DEBUG!
}

void SendBreak()
{
	// io.pinMode(0, Dir, OUTPUT); //Make sure direction is set to output
	// io.pinMode(0, FOut, OUTPUT); //Make sure the force out pin is in output mode
	io.digitalWrite( Dir, HIGH); //Set direction to output
	io.digitalWrite( FOut, LOW); //Set low to force output high
	delay(13); //Wait for bus to acnowledge action
	io.digitalWrite( FOut, HIGH); //Stop forcing output
}

void Mark(unsigned long Period)
{
	// io.pinMode(0, Dir, OUTPUT); //Make sure direction control pin is set as an output
	digitalWrite(TX, 1); //Preempt value before turning output on
	delay(1);
	pinMode(TX, OUTPUT); //Make sure transmit pin is set as output
	io.digitalWrite( Dir, HIGH); //Set direction to output
	digitalWrite(TX, 1); //Begin marking condition
	delay(Period); //Wait for a given marking period
	// digitalWrite(TX, 0); //Stop marking  
}

void Space(unsigned long Period)
{
	// io.pinMode(0, Dir, OUTPUT); //Make sure direction control pin is set as an output
	pinMode(TX, OUTPUT); //Make sure transmit pin is set as output
	io.digitalWrite( Dir, HIGH); //Set direction to output
	digitalWrite(TX, 0); //Begin spacing condition
	delay(Period); //Wait for a given marking period
	digitalWrite(TX, 1); //Stop spacing
}

// void SendCommand()

void ReleaseBus() 
{
	// io.pinMode(0, Dir, OUTPUT); //Make sure direction pin is set as an output
	io.digitalWrite( Dir, LOW); //Set direction to input
}

String SendCommand(String Command) 
{
	SendBreak(); //Send break to start message
	Mark(MARKING_PERIOD); //Mark for standard period before command
	// pinMode(TX, INPUT);
	// delay(1);
	Serial1.begin(1200, SERIAL_7E1);
	Serial1.print(Command); 
	Serial1.flush(); //Make sure data is transmitted before releasing the bus
	delay(1); //DEBUG! Return to 1ms??
	ReleaseBus(); //Switch bus to recieve 
//	io.digitalWrite(4, HIGH); //DEBUG! Turn off output buffer!
	// char Var = Serial.re

	unsigned long LocalTime = millis();
	char Data[100] = {0}; //Make data array for storage FIX! Change length to not be arbitrary
	bool GotData = false; //Used to keep track of terminating character has been recieved 
	int Pos = 0; //Keep track of position in data array
	while(!GotData && (millis() - LocalTime) <  TimeoutStandard) {
		if(Serial1.available() > 0) {
			Data[Pos] = Serial1.read(); //If byte is available, read it in
			Pos++; //Increment position
		}
		if(Data[Pos] == '\n') GotData = true; //Set flag if end character is read in
	}
	String Val = String(Data); //Convert to String
	Val.trim(); //Get rid of any trailing characters 
	// while(Serial1.available() < 3 && (millis() - LocalTime) <  TimeoutStandard);
	// String Val = Serial1.readStringUntil('\r');
	// Serial.println(Val);
//	io.digitalWrite(4, LOW); //DEBUG! Turn on output buffer!
	return Val; 
}

///////////////////DUMB PATCH INCOMING!//////////////////////////////////
// void SetPinMode() { 
// 	Wire.beginTransmission(ADR);
// 	Wire.write(DIR);
// 	Wire.write(0x00);
// 	Wire.endTransmission();
// }

// void SetPullups() {
// 	Wire.beginTransmission(ADR);
// 	Wire.write(PU);
// 	Wire.write(0xFF);
// 	Wire.endTransmission();
// }

// // void io.digitalWrite(uint8_t Pin, uint8_t State) {
// // 	uint8_t Val = ReadByte(LAT);
// // 	if(State) Val = Val | (1 << Pin);
// // 	if(!State) Val = Val & (~(1 << Pin)); 

// // 	Wire.beginTransmission(ADR);
// // 	Wire.write(LAT);
// // 	Wire.write(Val);
// // 	Wire.endTransmission();
// // }

// uint8_t ReadByte(uint8_t Reg) {
// 	Wire.beginTransmission(ADR);
// 	Wire.write(Reg);
// 	Wire.endTransmission();

// 	Wire.requestFrom(ADR, 1);
// 	return Wire.read();
// }

void SetDefaultPins()
{
	Serial.println(io.begin()); //DEBUG!
	io.pinMode(SENSE_EN, OUTPUT); //Set sense control as output
	io.digitalWrite(SENSE_EN, HIGH); //Default sense to on - NOTE: For proper sequencing, this must be done BEFORE each enable line is driven high
	for(int i = 0; i < 8; i++) { //Enable all power, then all data
		io.pinMode(i, OUTPUT); 
		io.digitalWrite(i, HIGH); 
	} 

	for(int i = 8; i < 12; i++) { //Set FAULT lines as input pullups
		io.pinMode(i, INPUT_PULLUP);
	}

	io.pinMode(POS_DETECT, INPUT); //Set position detect as normal pullup (has external pullup)
	// io.pinMode(SENSE_EN, OUTPUT); //Set sense control as output
	// io.digitalWrite(SENSE_EN, HIGH); //Default sense to on 
}

void VoltageSense() //Voltage sense (AKA Sensor0)
{
	Serial.print(">Voltage Sense:\n");
	// digitalWrite(I2C_EN, LOW); //Turn off external I2C
	io.digitalWrite(SENSE_EN, HIGH); //Make sure sense power is turned on
	ioSense.begin(); //Initalize voltage sensor IO expander
	for(int i = 0; i < 4; i++) { //Set all pins to output
		ioSense.pinMode(i, OUTPUT); 
	}
	ioSense.digitalWrite(MUX_EN, LOW); //Turn MUX on 
	int SenseError = adc.Begin(); //Initialize ADC 
	if(SenseError == 0) { //Only proceed if ADC connects correctly
		adc.SetResolution(18); //Set to max resolution (we paid for it right?) 

		ioSense.digitalWrite(MUX_SEL2, HIGH); //Read voltages
		for(int i = 0; i < 4; i++){ //Increment through 4 voltages
			ioSense.digitalWrite(MUX_SEL0, i & 0b01); //Set with lower bit
			ioSense.digitalWrite(MUX_SEL1, (i & 0b10) >> 1); //Set with high bit
			delay(1); //Wait for voltage to stabilize
	  		Serial.print("\tPort");
	  		Serial.print(i);
	  		Serial.print(":");
	  		Serial.print(adc.GetVoltage(true)*VoltageDiv, 6); //Print high resolution voltage
	  		Serial.print(" V\n");  
		}
		ioSense.digitalWrite(MUX_SEL2, LOW); //Read currents
		for(int i = 0; i < 4; i++){ //Increment through 4 voltages
			ioSense.digitalWrite(MUX_SEL0, i & 0b01); //Set with lower bit
			ioSense.digitalWrite(MUX_SEL1, (i & 0b10) >> 1); //Set with high bit
			delay(1); //Wait for voltage to stabilize
	  		Serial.print("\tPort");
	  		Serial.print(i);
	  		Serial.print(":");
	  		Serial.print(adc.GetVoltage(true)*CurrentDiv*1000, 6); //Print high resolution current measure in mA
	  		Serial.print(" mA\n");  
		}
	}
	else Serial.print("\tFAIL!\n");
	ioSense.digitalWrite(MUX_EN, HIGH); //Turn MUX off
	// digitalWrite(I2C_EN, HIGH); //Turn on external I2C
}

void AuxVoltageSense()
{
	io.digitalWrite(DATA_EN1 + 3, LOW); //Set MUX to analog output
	Serial.print(">Aux Voltage Sense:\n");
	adcAux.begin(); //Initalize the MCP3221
	Serial.print("\t");
	Serial.print(adcAux.getVoltage(3.3)*1000.0); //Print voltage in mV, calculate for 5V supply 
	Serial.print(" mV\n"); 
}

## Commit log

2021-10-01 Initial layout complete
    [Talon_SDI12.brd, Talon_SDI12.sch]
2021-10-08 Layout and cleanup done, review needed
    [Talon_SDI12.brd, Talon_SDI12.sch]
2021-10-12 Layout, gerbers, and BoM for v0.0 - submitted to fab
    [Talon_SDI12.brd, Talon_SDI12.sch, Talon_SDI12_0v0_BoM.csv]
2021-10-14 V0.1 Updates - Added EEPROM
    [Talon_SDI12.brd, Talon_SDI12.sch]
2021-10-14 Generated documentation for v0.1 quote
    [Talon_SDI12_0v1_BoM.csv]
2021-10-22 Updated demo to support aux voltage sensor
2021-11-22 Updated v1.0, sent to fab
    Made fixes for v1.0:
    - Fixed bypass control
    - Changed arrangement of 12V reg
    - Added filter lines (clitch protection) to sense lines
    - Flipped Talon connector port pinout
    - Adjusted port 4 topology to deal with pulldown issue
    - Moved MUX (U11/U15) to prevent soldering issues
    - Moved U7 to prevent bumping
    - Added additional protection circuitry on SDI-12 outputs
    [Talon_SDI12.brd, Talon_SDI12.sch]
2021-11-23 Updated paste layout
    [Talon_SDI12.brd]
2021-11-23 v1.1 Updates
    moved port 1 and port 4, sent to fab
    [Talon_SDI12.brd, Talon_SDI12.sch]
2021-12-10 Added v1.1 BoM
    [Talon_SDI12_1v1_BoM.csv]
2021-12-10 Added v1.1 mechanical files
    [Talon_SDI12_1v1.STL, Talon_SDI12_1v1.dxf]
2021-12-10 v1.2 updates
    Fixed physical overlap in current limit circuit
    [Talon_SDI12.brd, Talon_SDI12.sch]
2022-02-18 Added v1.2 BoM, corrected demo interface
    [Talon_SDI12_1v2_BoM.csv]
2022-02-25 v1.3 Updates
    [Talon_SDI12.brd, Talon_SDI12.sch]
2022-04-06 Updates for BoM
    [Talon_SDI12.brd, Talon_SDI12.sch, Talon_SDI12_1v3_BoM.csv]
2022-04-06 Added mount file
2022-04-06 Updated EEPROM part number
    [Talon_SDI12.brd, Talon_SDI12.sch, Talon_SDI12_1v3_BoM_2022-04-06.csv]
2022-04-22 Updated to v1.4
    Added loopback functionality, replaced MCP23018 with PACL9535A, fixed inverter (U23) model, fixed attributes on schematics
    [Talon_SDI12.brd, Talon_SDI12.sch]
2022-04-25 Added gerbers for v1.5
2022-04-25 Added gerbers for v1.4
2024-09-01 Updated README and board images
2024-11-02 Added production info
    [Talon_SDI12_1v4_BoM_2022-05-04.csv]

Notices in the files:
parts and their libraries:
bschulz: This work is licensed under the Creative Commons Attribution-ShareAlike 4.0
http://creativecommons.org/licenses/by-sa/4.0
